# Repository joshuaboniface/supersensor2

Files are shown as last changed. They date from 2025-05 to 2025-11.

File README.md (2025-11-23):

# Repository Unification

For future expandability to make my life a bit easier, I'm deprecating this repo
and moving the SuperSensor 2.x code back to the original https://github.com/joshuaboniface/supersensor
repository in the branch `v2.x`. Sorry for the inconvenience!

Please update your package configuration URLs to the following:
```
packages:
  joshuaboniface.supersensor: github://joshuaboniface/supersensor/supersensor.yaml@v2.x
```

This repository will remain with a package redirect for a while but will no longer be the source of truth
for Issues, etc. Please direct all activity to that other repository instead!

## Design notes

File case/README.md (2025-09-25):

# SuperSensor 2.x Case

This is a 3D-printable case for the SuperSensor 2.x all-in-one voice, motion,
presence, temperature/humidity/air quality, and light sensor.

This case provides a convenient way to cover up the SuperSensor's PCB, either
for aesthetics or to help protect it from harsh environments.

You can [tinker the design on TinkerCAD here](https://www.tinkercad.com/things/1HT3fyNbln0-supersensor-case).
The case design and images in this folder are licensed under the Creative Commons
Attribution-ShareAlike (BY-SA) 4.0 license.

## Printing

Provided here are 5 `.obj` CAD files designed for slicing and printing with
any slicer software and 3D printer.

### `body.obj`

This is the main body of the case which houses the PCB. It includes an opening
for the insertion of a USB-C cable of "normal" size, which should fit most cables.

This part should be printed in a solid, durable material of any colour you wish.

### `face.obj`

This is the front face of the case. It clips into the body with 4 triangular
grip clips, and has 5 openings:
  * A large rectangle for the insert below.
  * A large circle for the PIR and am312 extension tube below.
  * A small flush hole for the TSL2591 light sensor.
  * A small funneled hole for the SGP41 air quality sensor.
  * A small funneled hole for the SHT45 temperature/humidity sensor.

**NOTE**: This design can affect the baseline readings of these sensors!
Specifically, the TSL will report much lower ambient light levels (up to 30 lux)
unless light is directly facing it; and the SHT45 will hover about 6 degrees
higher than the exposed PCB would from my testing. Take these into account in
your usage!

This part should be printed in a solid, durable material of any colour you wish.

### `insert.obj`

This insert fits into the large rectangle in the face, and provides a diffuser
for the feedback/status LEDs, including an opening for the INA microphone. It
is inserted into the face separately during assembly, though a multi-material
printer could concievably print it into the face during printing.

This part should be printed in a solid, durable material in **a natural or transluscent** colour (it must let light through).

### `am312-tube.obj`

This round tube provides additional buffering for the AM312 over the face, extending
it by 8mm to completely cover the AM312 body. It attaches to the face over the large
circular hol separately during assembly.

This part should be printed in a solid, durable material in any colour you wish.

### `usb-extension.obj` (optional)

This square tube provides additional coverage of the USB cable opening for situations
where that may be needed, either for "weatherproofing", cable management, or mounting.
It attaches over the opening in the body and should fit most cables. Note that USB
insertion may be harder with this on so consider that carefully during cable selection;
a long boot cable is a plus here.

This part should be printed in a solid, durable material in any colour you wish.

## Assembly

To begin, print the parts above as indicated; default slicer settings should be sufficient.
We will exclude the USB cable opening extension for this assembly, but its installation
is straightforward.

Lay out the parts; you will need:

    * The body, face, insert, and AM312 tube parts.
    * Superglue
    * A toothpick (if not using a precision superglue applicator)
    * A hard, flat surface (I use a vice)

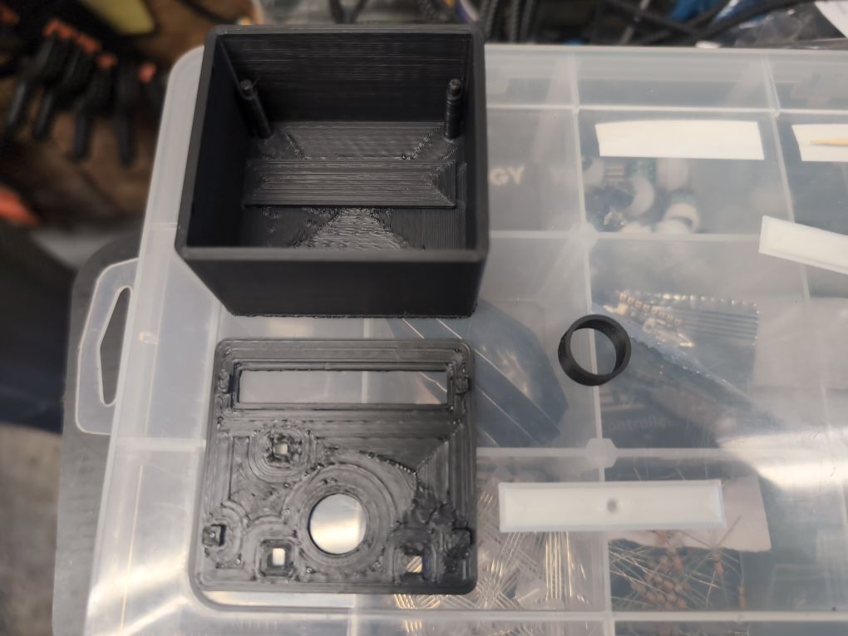
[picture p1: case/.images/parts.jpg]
Parts
   

### Face

1. Place the face face-down (clips up), and place dabs of superglue at the corners of the
   insert openings.

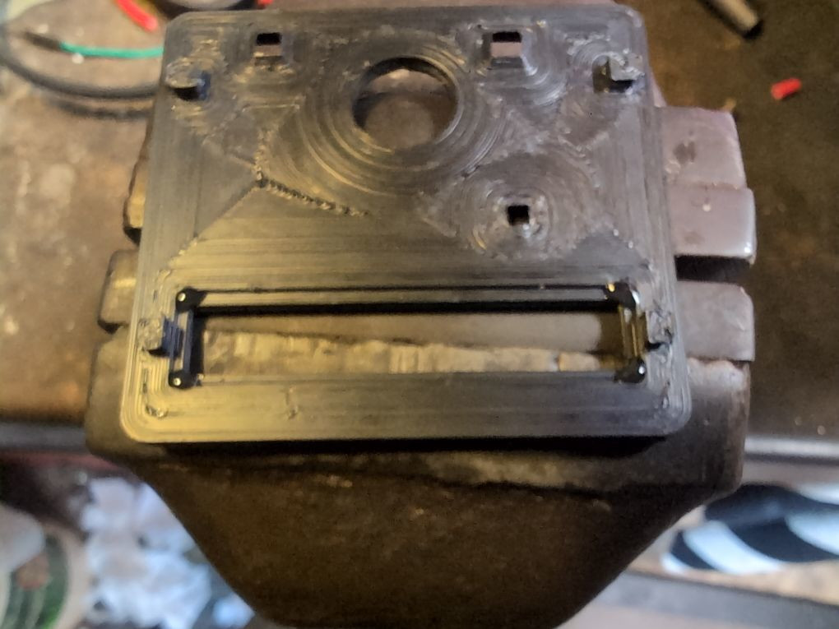
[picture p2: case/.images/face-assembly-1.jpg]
Face Assembly 1
   

2. Spread the superglue along the inner edges with the toothpick; or, combine 2+3 by using
   a precision superglue applicator. You need very little glue here; avoid extra ooze!

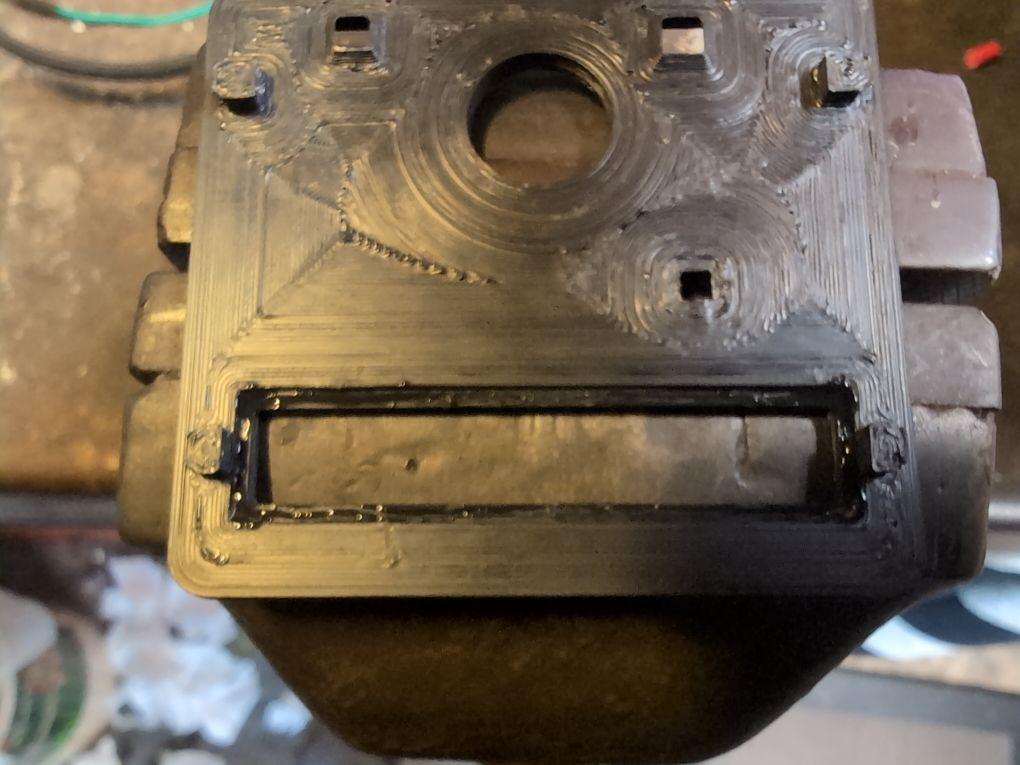
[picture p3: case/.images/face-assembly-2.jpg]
Face Assembly 2
   

3. Firmly place the insert face-down into the hole; the overlap edges should match.

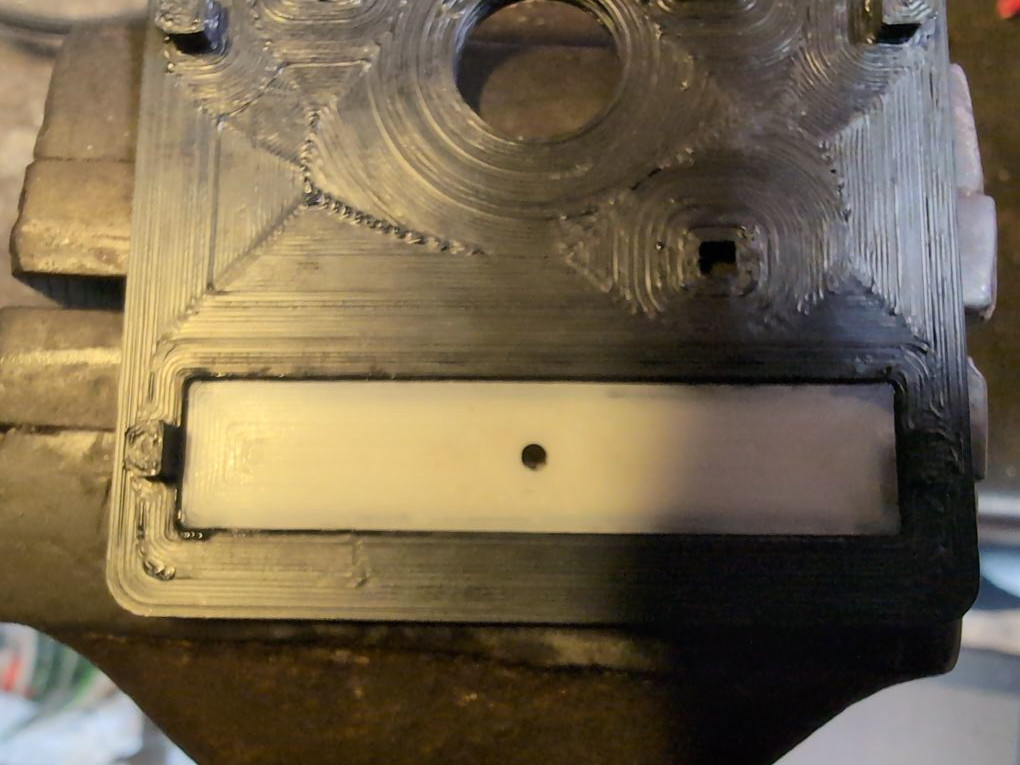
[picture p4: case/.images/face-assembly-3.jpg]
Face Assembly 3
   

4. Apply firm pressure to both sides of the insert with your thumbs, a vice, or another
   pressing object, until the glue can set up (15-30 seconds).

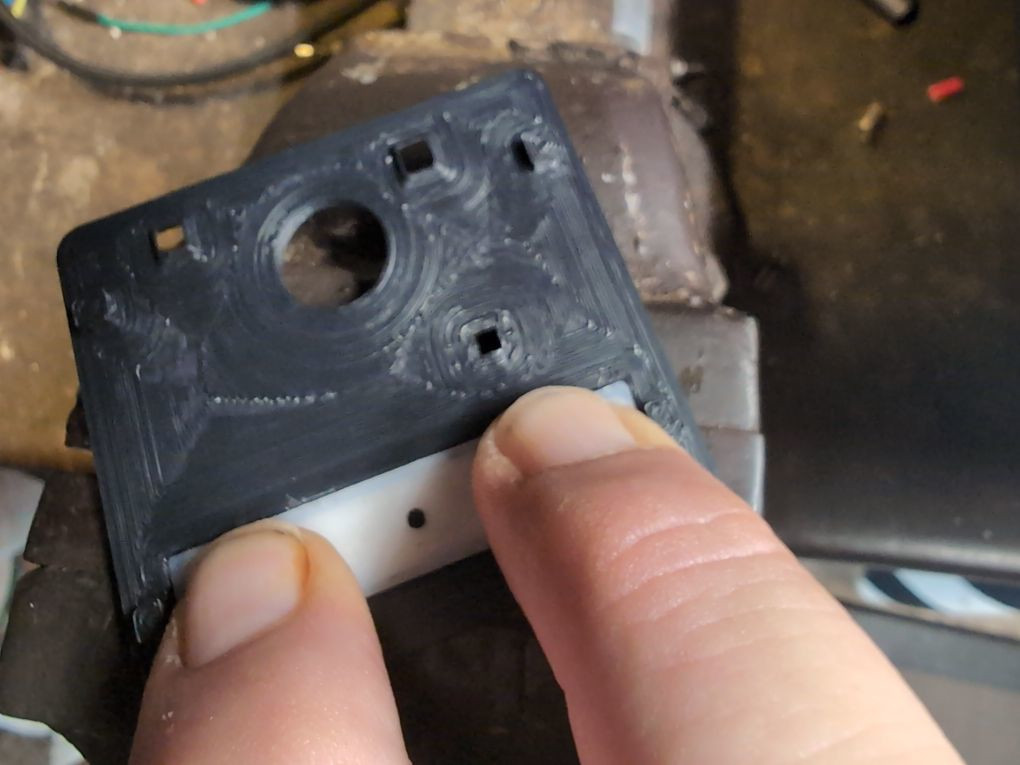
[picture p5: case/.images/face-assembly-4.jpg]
Face Assembly 4
   

5. Flip over the face; the insert should now be solidly affixed. Clean up any oozing superglue
   with a paper towel or lint-free rag.

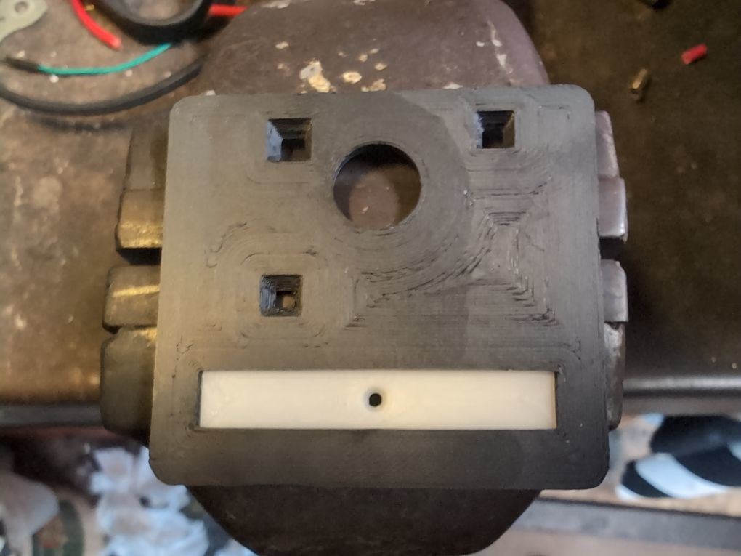
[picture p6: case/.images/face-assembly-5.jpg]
Face Assembly 5
   

6. Place a small amount of superglue on your toothpick tip; if using a precision superglue
   applicator, skip this step.

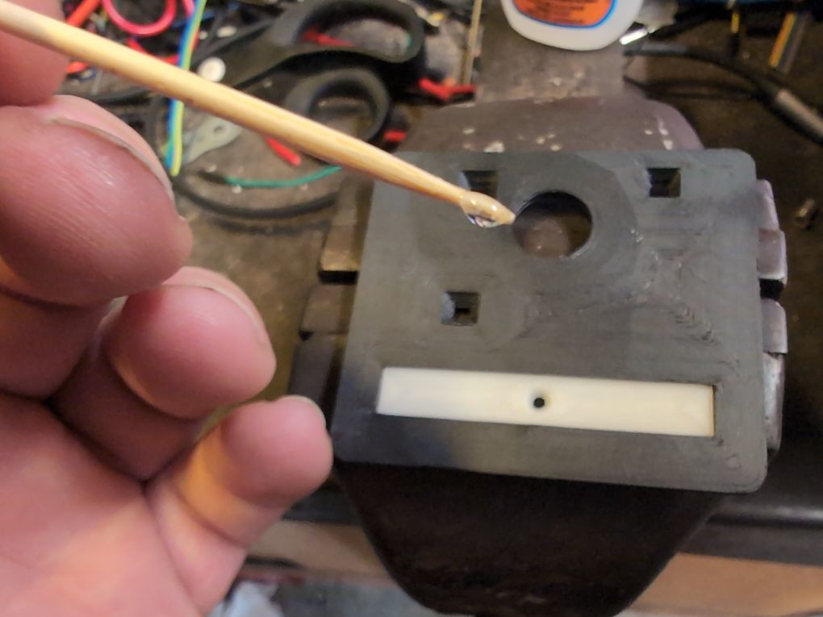
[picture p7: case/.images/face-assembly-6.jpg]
Face Assembly 6
   

7. Gently spread the superglue around the circular opening (or apply using a precision superglue
   applicator); you want the bead to be no more than 1mm wide to avoid ooze.

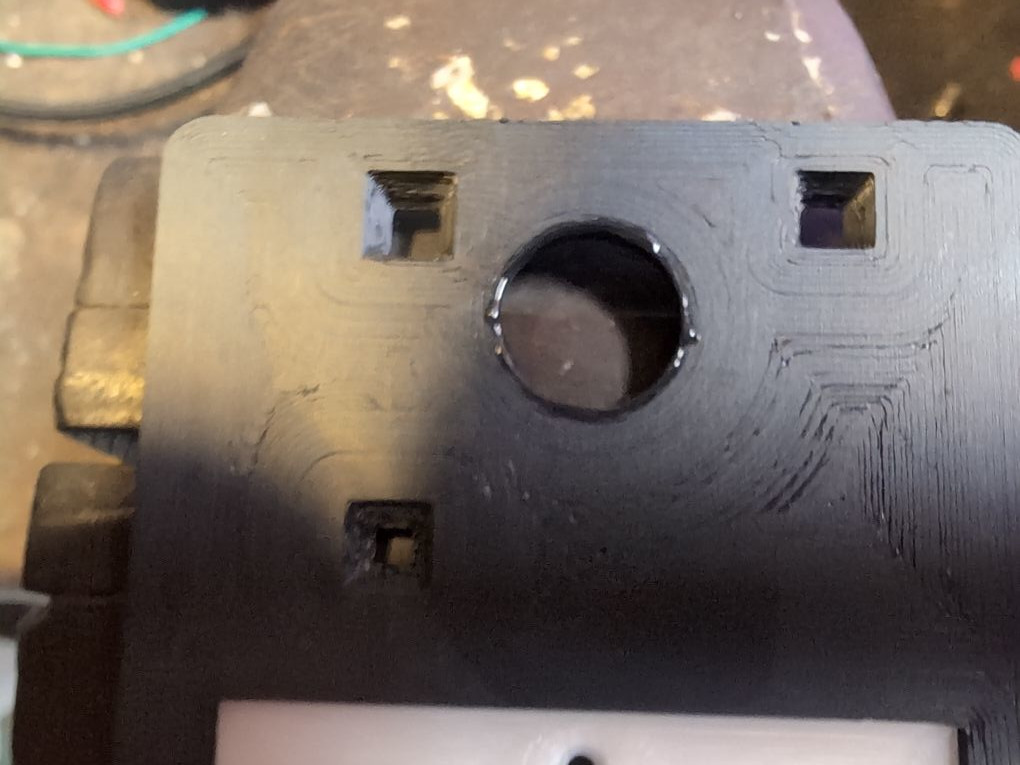
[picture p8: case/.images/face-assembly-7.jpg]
Face Assembly 7
   

8. Line up the AM312 tube, and firmly press it down to seal. Clean up any oozing superglue
   with a paper towel or lint-free rag.

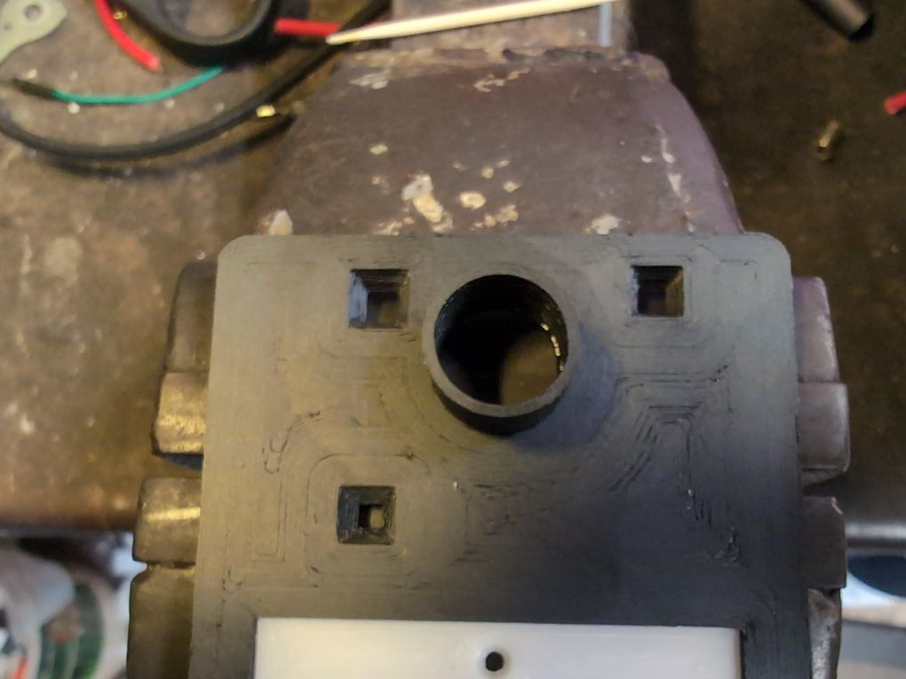
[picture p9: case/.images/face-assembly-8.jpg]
Assmbly 8
   

You will now have a completed face assembly and are ready to install the actual SuperSensor.

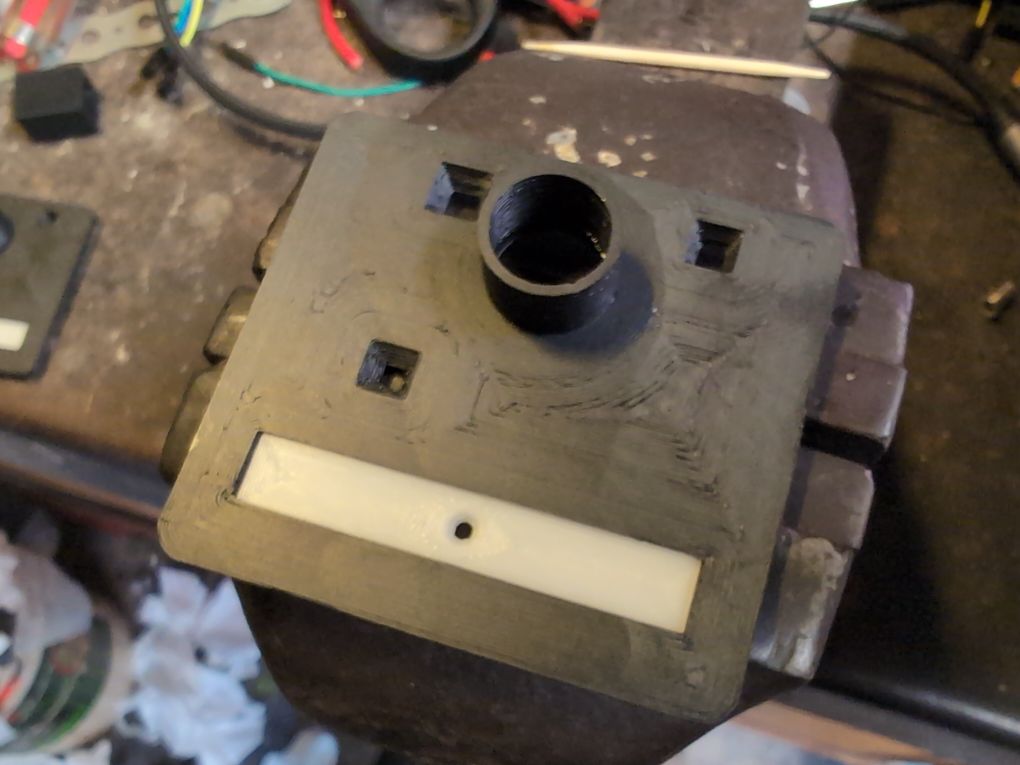
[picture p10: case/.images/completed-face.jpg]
Completed Face


### Body

1. Gently insert the SuperSensor board into the case body, lining it up with the four standoffs.
    The ESP32 should b firmly sitting on the bottom (it should require no force).

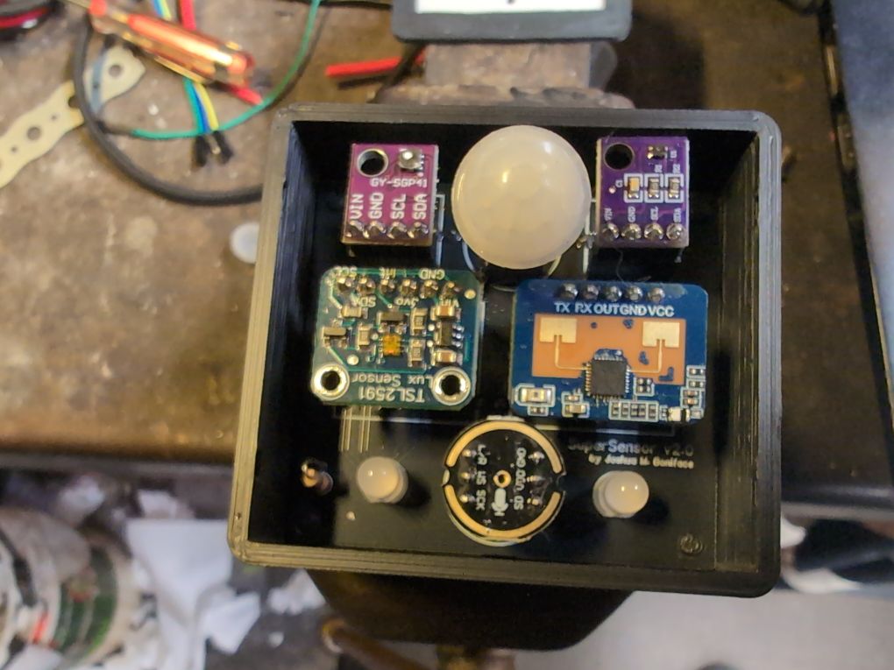
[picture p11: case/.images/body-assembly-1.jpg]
Body Assembly 1
   

   You can verify that the USB plug is sitting flush on the base.

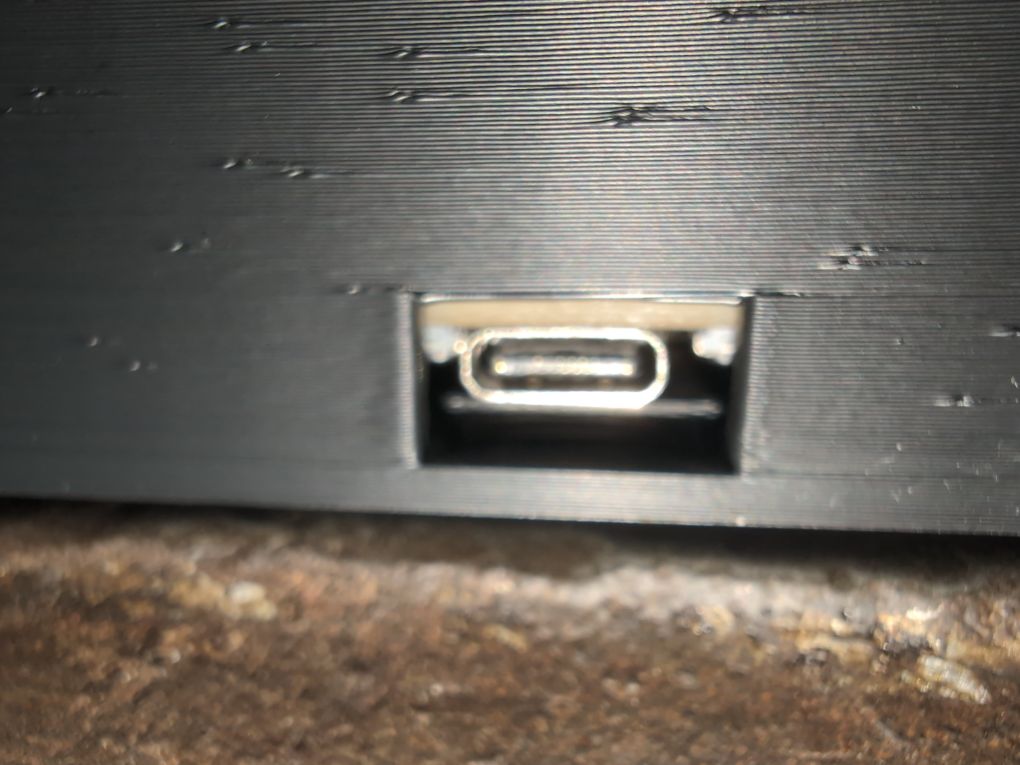
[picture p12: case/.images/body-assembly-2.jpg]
Body Assembly 2
   

2. Remove the top cap of the AM312.

3. Place the face over the AM312.

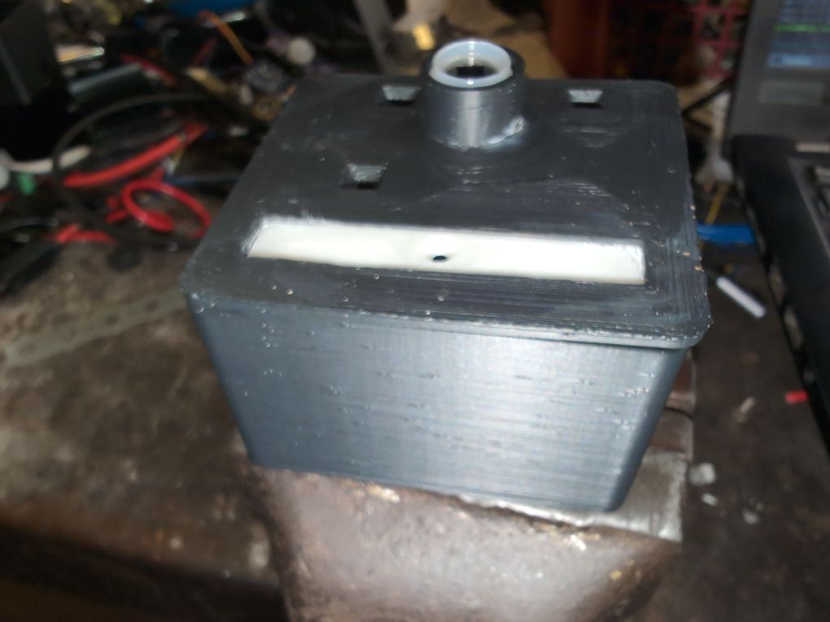
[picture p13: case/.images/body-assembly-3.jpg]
Body Assembly 3
   

4. Line up the clips on one side (I prefer the left). Then using a gentle squeezing motion, apply
   pressure to the sides of the case on the right side while also applying lateral pressure on
   the face towards the inserted clips. This picture is a one-handed demonstration, applying a
   squeezing pressure between my thumb and middle finger and a downwards pressure with my index
   finger to provide force; using two hands is advised.

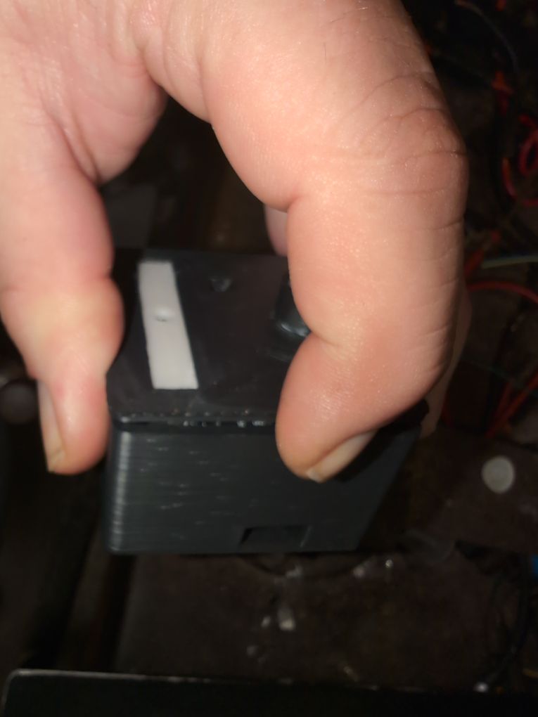
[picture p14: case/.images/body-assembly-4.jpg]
Body Assembly 4
   

5. While doing the previous step, ensure that the 3 sensor holes are lined up with their corresponding sensors.

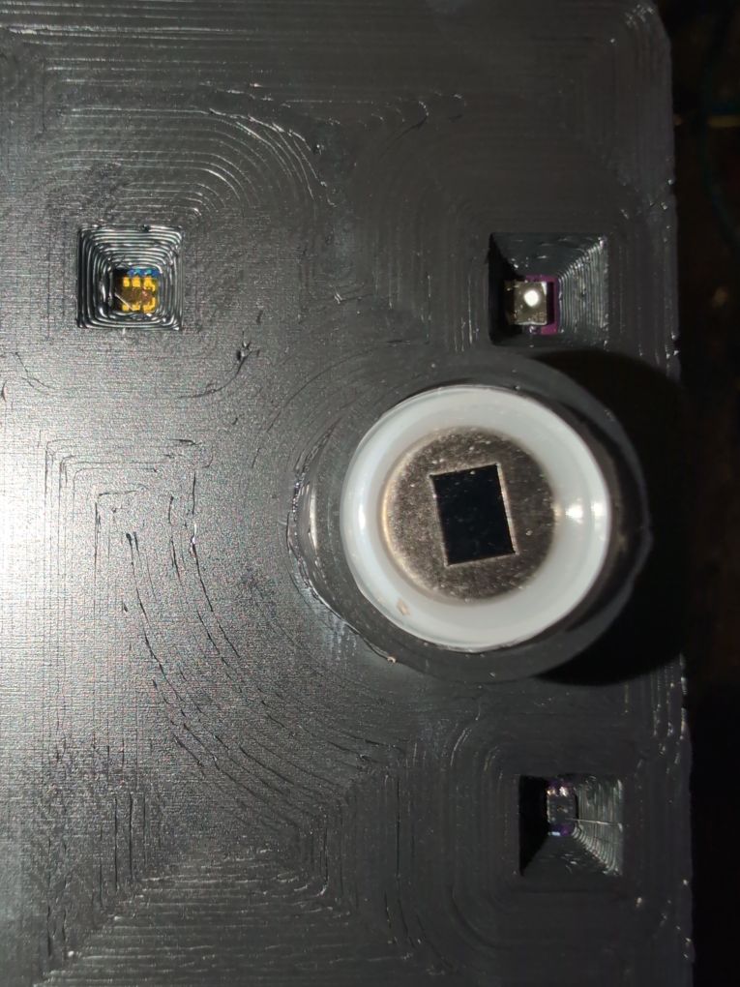
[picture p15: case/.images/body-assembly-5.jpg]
Body Assembly 5
   

6. Press the face into the body so that all 4 clips are making contact.

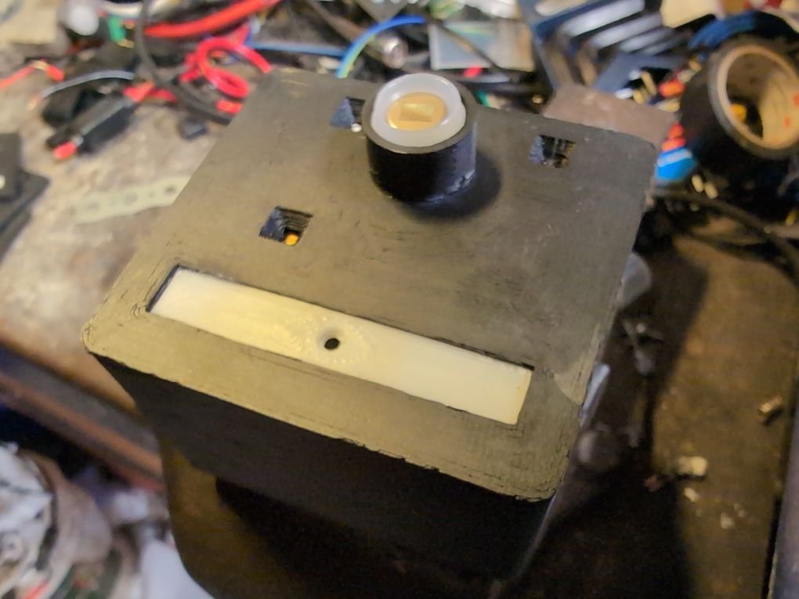
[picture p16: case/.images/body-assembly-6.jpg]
Body Assembly 6
   

7. Reinstall the top cap of the AM312; it should have a snug fit against the tube.

You now have an assembled case!

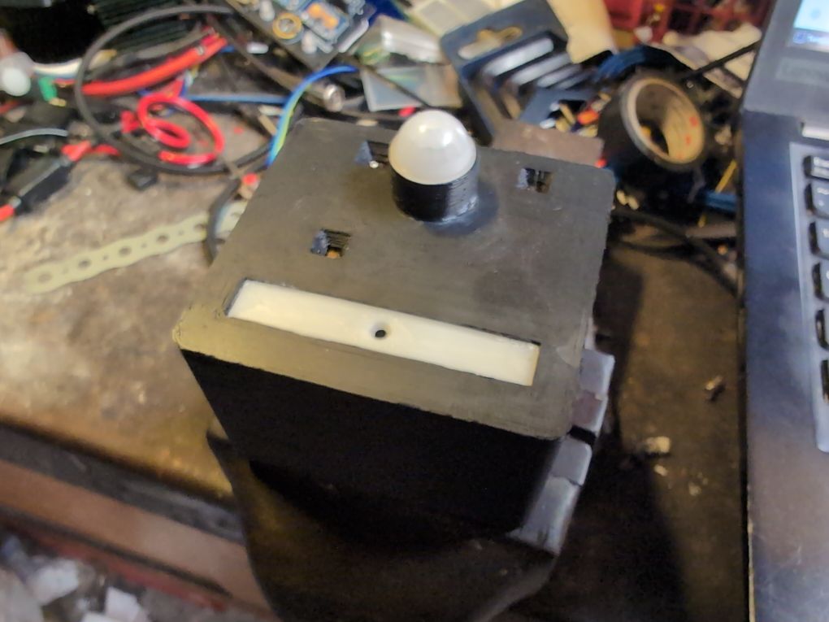
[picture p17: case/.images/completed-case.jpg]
Completed Case


As a further step, consider placing a line of tape around the face-body joint. The locking clip
design was made with printing in mind, and does have some play here.

## Installation

You may either mount the SuperSensor by its USB plug (as with a bare board design), or by attaching
a mounting piece to the case. Enjoy your newly-enclosed SuperSensor with diffused status LEDs!

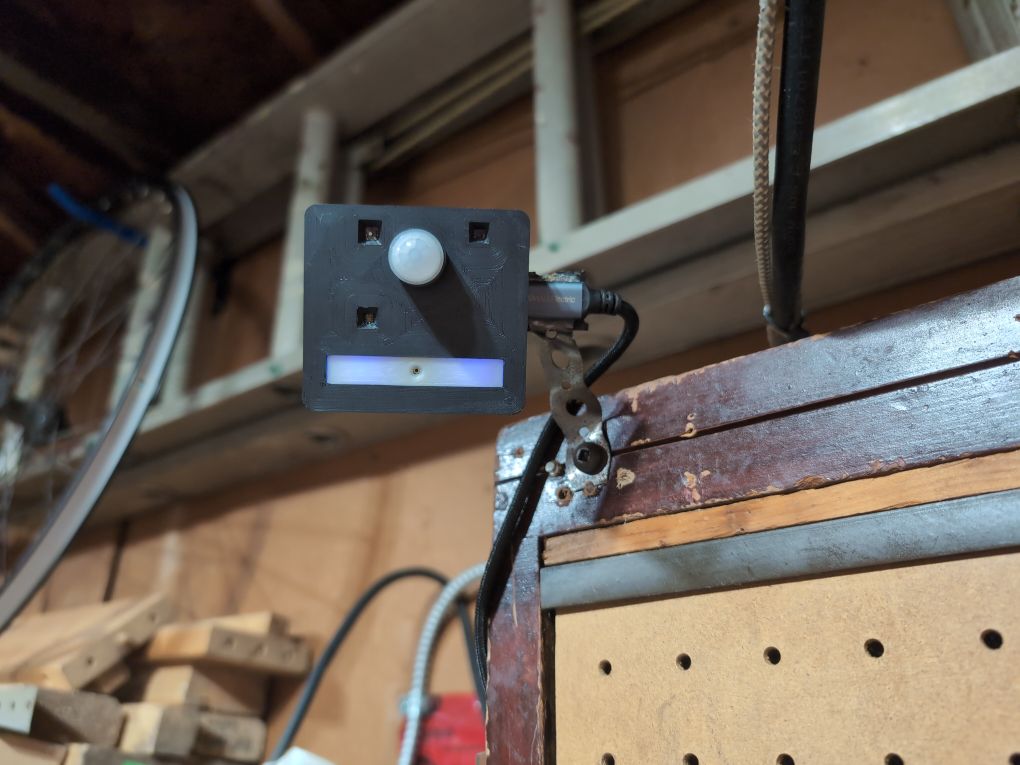
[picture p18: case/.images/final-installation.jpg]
Final Installation


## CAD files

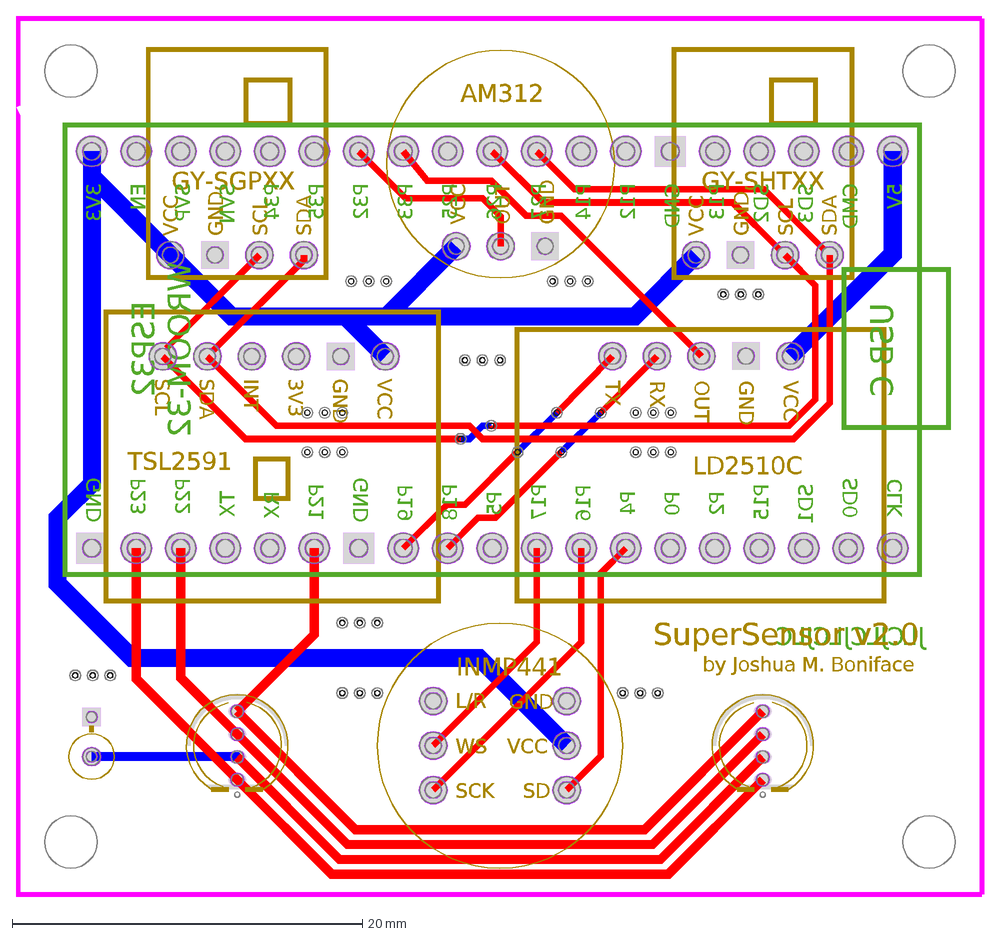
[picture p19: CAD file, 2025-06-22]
board/supersensor.dxf
JLCJLCJLCJLC
SuperSensor v2.0
by Joshua M. Boniface
AM312
GND
VCC
OUT
GY-SGPXX
SCL
SDA
GY-SHTXX
WS
L/R
SCK
SD
INMP441
LD2510C
RX
TX
TSL2591
3V3
INT
EN
SVP
SVN
P34
P35
P32
P33
P25
P26
P27
P14
P12
P13
SD2
SD3
CMD
5V
P23
P22
P21
P19
P18
P5
P17
P16
P4
P0
P2
P15
SD1
SD0
CLK
ESP32
WROOM-32
USB C

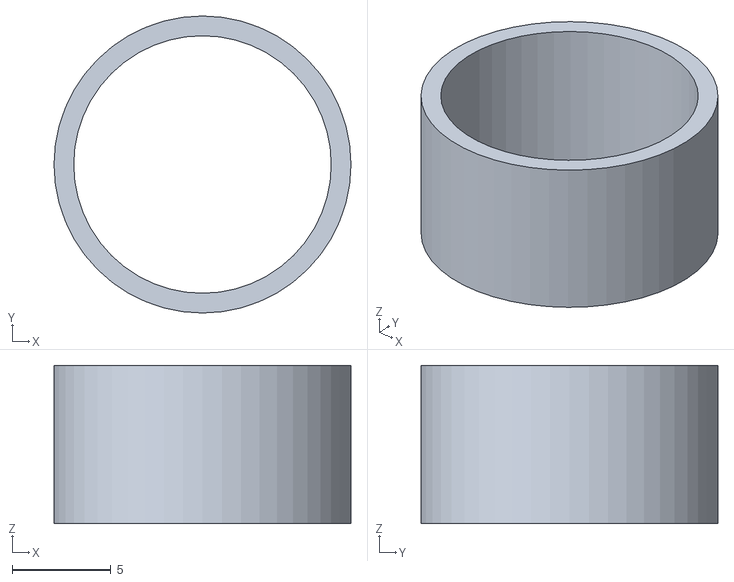
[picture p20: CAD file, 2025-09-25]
case/am312-tube.obj
15.0 x 15.0 x 8.00

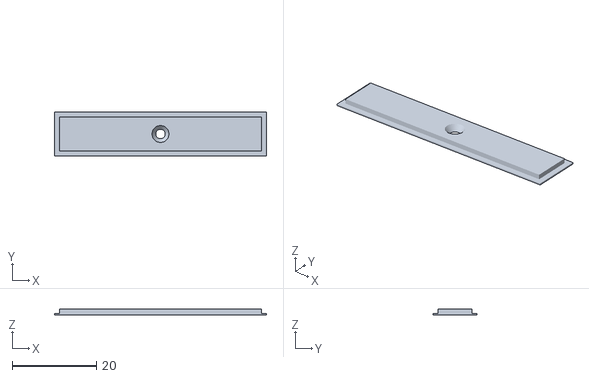
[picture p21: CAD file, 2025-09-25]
case/insert.obj
50.4 x 10.4 x 1.32

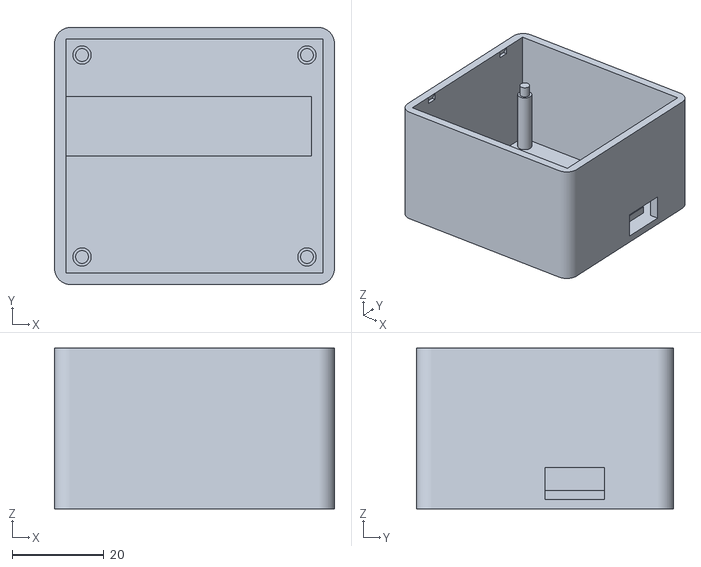
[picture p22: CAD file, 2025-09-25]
case/body.obj
61.0 x 56.0 x 35.0

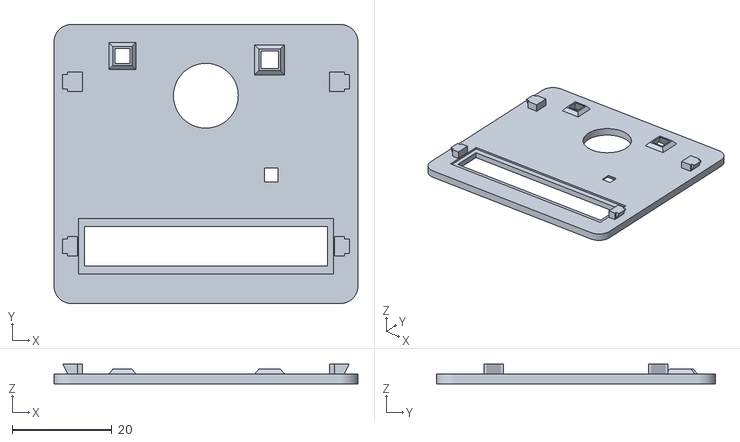
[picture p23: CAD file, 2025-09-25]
case/face.obj
61.0 x 56.0 x 4.00

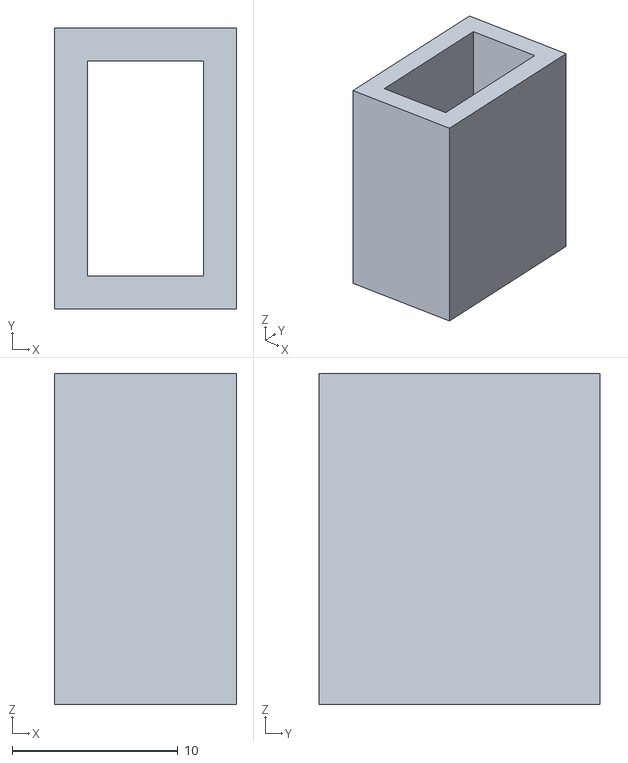
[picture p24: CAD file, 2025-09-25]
case/usb-extension.obj
11.0 x 17.0 x 20.0

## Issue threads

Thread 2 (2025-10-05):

Strange crashes in recent revisions with ESP32-WROOM-32D

joshuaboniface, 2025-10-05:
Of my 12 current units, 9 are running an older ESP32-WROOM-32 (no `D`/`S`/`U`), while 3 are running the ESP32-WROOM-32D. These were all purchased from the same seller in the same HW-395 form factor (https://www.aliexpress.com/item/1005006019875837.html as linked in the README) but at varying times, and it seems they've silently switched over.

There have been several major problems I've been encountering with Supersensor2 units made with these newer chips:

1. Random failures to initialize the microphone with repeated (100+/second) "Cannot allocate ring buffer" messages.
2. Random crashes (https://github.com/esphome/esphome/issues/11026 and some others) during voice operations.
3. More random crashes/panics when trying to free up heap memory (e.g. disabling Bluetooth, tweaking other settings, etc.)

Some tweaks I've done solve 1, but introduce their own unique crashes, though none of these problems exist on the non-D board.

I believe the issue is related to the lost ~15kb of heap memory on the 32D revision due to Espressif's memory allocation changes, but I can't truly be certain if that's the cause of 2, or if I have a bad batch.

I have several more on order (6 from the original seller, 5 from another, much more expensive, seller that still advertises as non-`D`/`S`/`U` models) to continue testing, but until this is sorted I DO NOT recommend folks buy the listed model to make Supersensor2's or you may have a bad time.

I see two ways forward:

* Be extremely careful about what HW-395 modules are purchased, and pay the premium for the older ESP32-WROOM-32.
* Move towards a Supersensor "2.5"/3, that would feature a much more robust chip directly SMD'd onto the PCB.

I like the idea of the second option long-term, even if it is a lot more development effort, but given that I already have "all" 12 Supersensor2's that I need in my house, and I just need to find 3 more non-`D`/`S`/`U` revisions, it might be too much cost for me personally. But if the project gets popular in any degree I may just do this to bite the bullet.

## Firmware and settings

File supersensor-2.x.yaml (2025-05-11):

---

###############################################################################
# SuperSensor v2.0 ESPHome configuration
###############################################################################
#
#    Copyright (C) 2025 Joshua M. Boniface <joshua@boniface.me>
#
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
###############################################################################

esphome:
  name: supersensor
  name_add_mac_suffix: true
  friendly_name: "Supersensor"
  project:
    name: joshuaboniface.supersensor
    version: "2.0"
  on_boot:
    - priority: 600
      then:
        - lambda: |-
            id(supersensor_occupancy).publish_state(false);
            id(pir_presence).publish_state(false);
            id(light_presence).publish_state(false);
            id(radar_presence).publish_state(false);
        - light.turn_on:
            id: output_led
            effect: flash_white
    - priority: -600
      then:
        - wait_until:
            api.connected:
        - delay: 5s
        - if:
            condition:
              switch.is_on: enable_voice_support
            then:
              - logger.log: "Initializing voice assistant on boot"
              - switch.turn_off: voice_support_active
              - delay: 2s
              - switch.turn_on: voice_support_active

dashboard_import:
  package_import_url: github://joshuaboniface/supersensor/supersensor-2.x.yaml

esp32:
  board: esp32dev
  framework:
    type: esp-idf
    version: 4.4.8
    platform_version: 5.4.0
    sdkconfig_options:
      CONFIG_ESP32_DEFAULT_CPU_FREQ_240: "y"
      CONFIG_ESP32_DEFAULT_CPU_FREQ_MHZ: "240"
      CONFIG_ESP32_DATA_CACHE_64KB: "y"
      CONFIG_ESP32_DATA_CACHE_LINE_64B: "y"
      CONFIG_ESP32S3_DEFAULT_CPU_FREQ_240: "y"
      CONFIG_ESP32S3_DEFAULT_CPU_FREQ_MHZ: "240"
      CONFIG_ESP32S3_DATA_CACHE_64KB: "y"
      CONFIG_ESP32S3_DATA_CACHE_LINE_64B: "y"
      CONFIG_SPIRAM_CACHE_WORKAROUND: "y"
      CONFIG_OPTIMIZATION_LEVEL_RELEASE: "y"

globals:
  - id: temperature_offset
    type: float
    restore_value: true
    initial_value: "0.0"

  - id: humidity_offset
    type: float
    restore_value: true
    initial_value: "0.0"

  - id: pir_hold_time
    type: int
    restore_value: true
    initial_value: "15"

  - id: light_presence_threshold
    type: int
    restore_value: true
    initial_value: "30"

  - id: occupancy_detect_mode
    type: int
    restore_value: true
    initial_value: "0"

  - id: occupancy_clear_mode
    type: int
    restore_value: true
    initial_value: "0"

  - id: last_api_connected_time
    type: uint32_t
    restore_value: no
    initial_value: "0"

script:
  - id: light_off
    then:
      if:
        condition:
          - binary_sensor.is_on: supersensor_occupancy
          - switch.is_on: enable_presence_led
        then:
          - light.turn_on:
              id: output_led
              brightness: 15%
              red: 1
              green: 1
              blue: 1
              transition_length: 1s
        else:
          - light.turn_off:
              id: output_led
              transition_length: 1s

  - id: pir_handler
    then:
      - lambda: |-
          id(pir_presence).publish_state(true);
      - while:
          condition:
            binary_sensor.is_on: pir_gpio
          then:
            - delay: !lambda 'return(id(pir_hold_time) * 1000);'
      - lambda: |-
          id(pir_presence).publish_state(false);

  - id: light_handler
    then:
      - lambda: |-
          if (id(tsl2591_lux).state >= id(light_presence_threshold)) {
            id(light_presence).publish_state(true);
          } else {
            id(light_presence).publish_state(false);
          }

  - id: occupancy_detect_handler
    then:
      - lambda: |-
          ESP_LOGD("occupancy_detect_handler", "Occupancy detect handler triggered");

          // Get the current values of our presence sensors
          bool pir = id(pir_presence).state;
          bool radar = id(radar_presence).state;
          bool light = id(light_presence).state;

          // Determine if PIR counts (2nd bit of presence_type)
          int pir_counts = (id(occupancy_detect_mode) & ( 1 << 2 )) >> 2;

          // Determine if Radar counts (1st bit of presence_type)
          int radar_counts = (id(occupancy_detect_mode) & ( 1 << 1 )) >> 1;

          // Determine if Light counts (0th bit of presence_type)
          int light_counts = (id(occupancy_detect_mode) & ( 1 << 0 )) >> 0;
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

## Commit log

2025-05-11 Rework room health score calculation
    [supersensor-2.x.yaml]
2025-05-12 Update board to 2.x revision
    [supersensor.dxf]
2025-05-17 Fix GPIO pin assignments
2025-05-19 Add SGP30 baseline sensors
2025-05-20 Explicitly set 0 max duty for SHT heater
2025-05-20 Add 5 minute moving average to Sensirion sensors
    Avoids constant wild shifts over time by performing a sliding window
    moving average over the last 20 results (at 15s intervals).
2025-05-24 Add debug sensor components
2025-05-25 Add icons to various sensors
2025-05-28 Add ESPHome version sensor
2025-06-15 Switch logging to DEBUG during testing
2025-06-22 Switch to SGP41 air quality sensor
    My testing with the SGP30 sensor proved fruitless, as various sensors
    would mis-report (under- and over-) levels and generally not be
    consistent with each other or reality. These sensors are simply too
    flaky with zero consistency.
    Instead, switch to the SGP41, which so far seems more robust and is used
    in other tools like the AirGradient One. We leverage their calculations
    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
2025-06-22 Update designs for SGPXX change
    [supersensor.dxf]
2025-06-24 Only fire light_off on occupancy change
    Avoids constantly turning off a held LED.
2025-07-17 Set update intervals for template sensors
2025-09-21 Ignore strapping warning on GPIO15
    This is a dummy component anyways, so it doesn't matter.
2025-09-21 Convert PIR GPIO to pulldown
    As per [1] this is the suggested configuration.
    [1] https://community.home-assistant.io/t/am312-motion-sensors-going-crazy/335073/10
2025-09-22 Add boot startup LED flashes
    Helpful to signal successful boot when enclosed.
2025-09-25 Increase glow brightness for case
2025-09-25 Add case files, instructions, and references.
    [am312-tube.obj, body.obj, face.obj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]
2025-09-25 Add case LICENSE
2025-09-30 Add ESP32 prefix to debug sensors
2025-10-05 Fix incorrect light value changes
    Using the force-off of light_off during presence detection change would
    sometimes cause the response LEDs to disable prematurely, since the
    on_state can trigger seemingly at random. Switch to using a separate
    handler for this, which will instead execute after a hold ends (and both
    our responses leverage holds so this works in all cases).
2025-10-10 Properly fix light-switching-while-holding bug
    Use a global to keep the state here, and set it while a hold is active,
    only clearing it afterwards. While held calls to `light_off` are skipped
    entirely.
2025-10-20 Add dynamic humidity calibration from temp offset
    With the physical limitations of the SuperSensor, we were able to
    compensate for the temperature differential due to internal heating from
    the ESP, but this compensation was not being taken into account by the
    humidity sensor.
    Add a compensation factor based on the offset to ensure humidity
    properly tracks the filtered temperature value.

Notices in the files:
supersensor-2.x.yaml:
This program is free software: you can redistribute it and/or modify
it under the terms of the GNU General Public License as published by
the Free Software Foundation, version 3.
